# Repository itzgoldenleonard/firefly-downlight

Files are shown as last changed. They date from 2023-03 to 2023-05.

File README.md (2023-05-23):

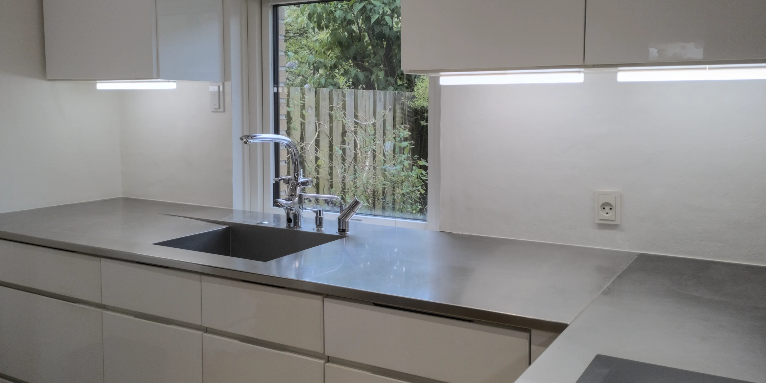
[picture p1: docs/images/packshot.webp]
Real picture of the lamps in use


# The firefly downlight

Functional, minimalist and modern downlight meant to be hung on the bottom of a cabinet or similar. Designed with kitchen use in mind but can be used wherever you like. The design is free and open source, easily moddable and 3d printable, so the barrier to manufacturing your own (customized) units is low.

## Organization

The first place you will want to look is the [`docs`](./docs) folder. Here you'll find all the information needed to do whatever you like with the project.

In the [`CAD`](./CAD) folder you'll find all of the OpenSCAD source files for the models of the actual lamp, the source files for a few optional extra tools and the libraries used in the design.

The [`Final`](./Final) folder contains the output files of the final design. That means each model has an STL 3d object file, a 3mf PrusaSlicer project file and a sliced gcode file for use with the craftbot+ 3d printer (if you have a different printer you'll need to re-slice it yourself)

Finally [`Test prints`](./Test%20prints) can mostly be ignored, it just contains tests that I used during the design process. If you're unsure that your printer's settings are correct they might be useful to test that everything fits together before printing the final parts, each test print has a markdown file associated with it explaining exactly what it contains.

## Contributing

This product is licensed under [CC-BY-SA 4.0](./LICENSE.md) which means that you have the freedom to manufacture it, study the source material, redistribute the source material and to modify it and redistribute your modified version, even for commercial purposes. As long as you give appropriate credit and redistribute your modified version under the same copyleft terms.

If you decide to make some of these lamps for yourself it would be great if you left some feedback and explained your findings. To help me or someone else improve on the design. Feedback is important so that we can know what we're doing right, what we're doing wrong, and so that we can share ideas and inspirations that foster creativity and design improvements.

If you have generally useful modifications to this project, either the design itself or the documentation, you're very welcome to make a pull request and get your additions merged into this repo. Just make sure not to use any non-free file formats or your pull request will be rejected. Also feel free to go crazy and make improvements or modifications that might not be relevant to anyone but yourself, but if it doesnt line up with my vision of the project dont expect it to be merged into **this** repo.

Be creative and make the best of it. I found out that these lamps are actually also great for soldering, so I designed a [little part](./CAD/tools/helping_hands_mount.scad) that you can use to mount it to a pair of helping hands. I'm sure there are plenty of other uses that I cant think of, so it's your turn now to do that, maybe think a little outside the box and dont be afraid to experiment.

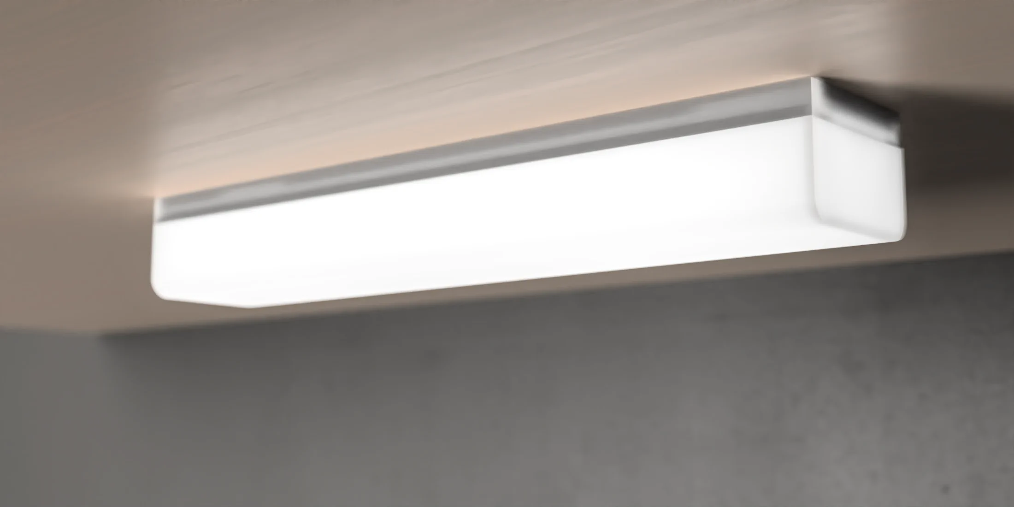
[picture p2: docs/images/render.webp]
Render of a lamp


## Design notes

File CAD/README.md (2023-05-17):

# Design files for the firefly downlight

This project is entirely made in OpenSCAD. Let me let you in on a little secret: *Openscad is pretty bad for projects of this size*. The code quality probably couldn't be much better, I've spent a long time making it as readable as possible, but I've had to get pretty hacky to get everything to work together. I'll walk you through how it all works on a high level though, if you want more detail the code itself is either pretty self explanatory or explained with comments.

## 1. Selecting the parts

It all starts in `main.scad`. This is the file you'll wanna open in OpenSCAD. There are 3 parts to a complete lamp, you can select which one you want in the customizer window in OpenSCAD. They are as follows:
- `mount` aka *lamp mount* is the part that you stick or screw to the bottom of wherever you want the lamp to hang
- `lamp` is the part that holds the metal sheet with the LED strips and wiring
- `diffuser` is the part that slides into the lamp part and prevents you from burning out your eyeballs by looking directly at the LEDs

## 2. The dimensions file

All the different files need access to a bunch of dimensions, many of which need to be shared across multiple different files. So all of the dimensions are put in the single single `dimensions.scad` file that's included (run) at the start of every other file. If you wanna change some measurements, the `dimensions.scad` file is your one stop shop. Some things might break if you change certain variables too much, so always verify that the model turned out the way you actually wanted if you change anything in `dimensions.scad`.

The dimension variables are all prefixed with D and similar dimensions are grouped together in a hashmap (called object by json) like structure. There's a function in the `utility.scad` file called `get` that can extract values of the variables inside the hashmap like structures. This is the hacky stuff I was talking about.

## 3. The lamp mount part

The code for the *lamp mount* is inside `lamp_mount.scad`. It's a relatively simple part and it only consists of primitives and a few *female mounts*. 

The distinction is between *lamp mount* and just *mount*, the *lamp mount* is the entire part that you actually print, but the *mount* (in `mount.scad`) is the sub part with the dovetails, which can be either male or female, in this case it's female. 

The mount actually also consists of a custom module called *dovetail* from the file `dovetail.scad`

## 4. The lamp part

The code for the *lamp* part is inside the aptly named `lamp.scad` file. It's considerably more complicated, it also has some *mounts*, these ones are male. 

Inside of the part is a metal *sheet*, which is obviously not 3d printed. The *sheet* is covered with some honeycomb mesh from an external library called `lib/honeycomb.scad`.

It also has some cutouts that the *diffuser* can slide into. These are actually the same dovetails (from `dovetail.scad`) that the *mounts* use, just cut in half. And that's about it.

## 5. The diffuser

The *diffuser* whose code is in `diffuser.scad` is the easiest part. It's pretty much just a single extruded 2d sketch with some *half dovetails* from `dovetail.scad` on the tips. It slides into the matching half dovetails on the *lamp* with only a single visible seam.

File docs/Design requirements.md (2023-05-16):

# Design requirements for the firefly downlights

LED strip kitchen lamps

- [ ] Durable
    - [ ] Food (and steam) resistant
    - [ ] Cleanable without taking damage
- [ ] Repairable
    - [ ] Every component needs to be easily replaceable
    - [ ] Cables need to be easy to unplug
    - [ ] Easy to install and uninstall from its place
- [ ] Beautiful
    - [ ] No external cables
    - [ ] Smooth surface
    - [ ] As few seams as possible
    - [ ] Thin
- [ ] Make good light
    - [ ] Sufficiently bright
    - [ ] Soft light
    - [ ] No light spots on the visible surface
    - [ ] Consistent color

# Problems with previous design

## Durability
- Base gets bendy
- Base becomes crunchy
- LED strips have peeled off the base
- Some of the LEDs have gone out

## Repairability
- The diffuser is hard to get off
- The base is hard to get off
- Cables aren't easy to unplug

## Visual
- Cable management has gone loose over time
- Color is inconsistent (probably the diffusers fault)

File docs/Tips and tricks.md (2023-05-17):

# What material to use

I used PLA and it worked well, but if you're worried about damage from the heat (which is a very valid concern) you should use a more heat resistant material like PETG or ASA. Obviously the diffuser needs to be printed in a white or translucent material because as much light as possible needs to pass through it, but it shouldnt be completely transparent because then it wouldnt have any effect at all. You could in theory print the other parts in a different color but I dont see why you would.

# Testing that the mount fits

The file [`Test prints/dovetail_mount_test_v1.6.tar.gz`](../Test%20prints/dovetail_mount_test_v1.6.tar.gz) contains some models a single mount that you can use to test fit the mounts on your parts individually

# Printing on top of the metal sheet

This is hard. Take a look at the [3mf file](../Final/lamp.3mf) for some inspiration. You need to get your bridging settings bang on. 

Make it print the first layer or 2 on top of the metal as solid layers and not honeycomb. The plastic coming out of the nozzle wont stick to the metal (gluestick helps but not much), only the plastic on either side of it, so it needs to touch that plastic as often as possible so that it has something to hang onto. 

I found that turning off thick bridges helped. By default it will probably want to bridge over the long side of the sheet, but playing around with the bridge flow ratio, in my case made it want to bridge over the short side of the sheet, which means that it sticks to the plastic much more often, your mileage may vary. I used a bridging speed of 45mm/s, that seemed to be not too fast but not too slow.

Another thing that helps a lot is starting with a freshly leveled bed, and when it gets to that first bridging layer, having your fingers on the bed levelling knobs and turning them while it's printing the first layer to get it to apply just the right amount of pressure. You want the plastic to come out onto the metal sheet, but you want it to be squezzed pretty hard or it wont stick. Because the sheet is never perfectly flat I needed to adjust it continously throughout the first layer. 

If you dont get a near perfect first layer it will come loose on the next layer and ruin the whole rest of the print.

# Drilling cable holes through the lamp

I used a metal sheet with holes already cut into it, so I could just use a hot needle to make the hole through the plastic. It might be smart to drill the hole in the metal sheet before inserting it into the lamp. But it shouldnt be too difficult to drill it after the fact. 

In the default configuration you have 2 LED strips on either side of the sheet with a 4mm gap between them. This leaves just enough room for a hole or 2 big enough to fit 2 dupont wires through.

# Attaching LED strips

I would suggest you drill the hole before attaching the LED strips to avoid damaging them. 

Because you're putting the LED strips directly on a conductive surface it's best to be safe and add a little strip of electrical or double sided tape between each conductive pad on the strip and the metal sheet. Also check with a multimeter that there's no connection.

The smartest way to orient the LED strips is so that one of them has the negative rail facing the middle of the lamp and the other has the positive rail facing the middle of the lamp. This makes soldering much easier.

# Soldering

I found that the best way to solder was to strip and pre-tin the wires (with flux), then attach the lamp to a solid surface and line up the wires with the pads on the LED strips. Then with a chisel tip on the iron I would heat up the pad and the wire and bring in an appropriate amount of solder, which melts quickly and flows right onto the pad, making a solid connection. Once it was soldered, then I'd route the cables through the hole out to the other side.

There's 14mm between the pads on the 2 LED strips. Prepare and pre bend the wires first, then solder like before, if you attached one end and the other doesnt quite line up there is a little wiggle room if you bend the middle of the cable.

## Connection diagram

You have to be quite precise because the height clearance is super tight. No criss crossing cables allowed or the diffuser wont fit. Here's a psuedo wiring diagram showing how I connected everything up:

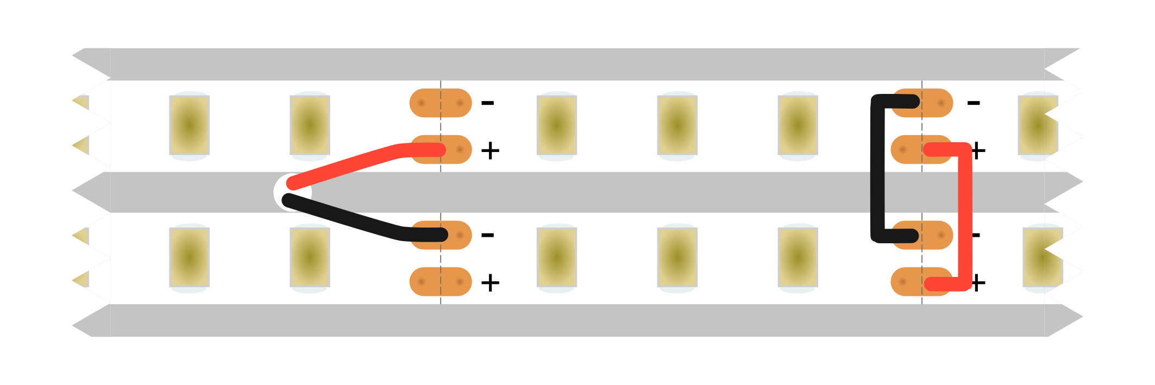
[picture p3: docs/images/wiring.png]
Wiring diagram


# Attaching connectors

Obviously you have to attach the connectors after you've soldered, I used common 0.1" dupont or jumper connectors, but maybe experiment with other connectors yourself. They kinda suck to attach because you need a crimping press to do it, but in my opinion it's well worth it when the alternative is wago connectors or soldering. You dont technically need connectors though.

# Power wire clearance

Whether you're retrofitting them onto an old cabinet or running cables specifically for these you do need to be mindful of the clearance that the power wires need. Because the lamp slides on from the side you cant just make a little circular hole in the bottom of the cabinet for the wires to go through. Additionally you will also need to fit a connector in the hole in the cabinet. You need to do some mental gymnastics to figure out the clearance. 

Imagine that the lamp is hanging and is attached to the cabinet. You need a hole that's big enough for the connectors to fit inside. But then when you go to remove the lamp you also need to extend the hole at least 25mm to the side that the lamp slides off. So make sure that the connectors also fit 25mm to the left or right of the initial hole.

Of course you also have to make sure that the wires never intersect with the individual mounts on the lamp mount, and the lamp mount needs to have a cutout that the wires can also always fit through.

# Grouping 2 together

The design is made for 2 lamps to sit right next to each other. The side that you slide the diffuser in from is a bit uglier that the other side, so that side needs to face the other lamp. When 2 lamps are grouped together like this they hide the ugly side and the left lamp slides off to the left and the right one slides off to the right, so both of them are actually possible to remove without interfering with the other one.

# Finishing

Sanding it completely smooth by hand looks very nice but also takes 10+ hours per lamp. So it's not exactly practical to do. I only sanded the rounded corners on mine and they look fine. But if you have a belt grinder you might be able to do it in a practical amount of time. Maybe try out sand blasting. Painting is probably not a good idea since the light has to shine through the plastic and the paint would probably just block it. If you have a good resin printer you might not even have to do any finishing. It depends on how picky you are with the finish, what you end up doing here. Making it with traditional plastic manufacturing methods instead of 3d printing is also a good option, although quite expensive.

# Simple/suggested mods

## Dimming

If you're concerned about overheating, or you just want to extend the life span of you LED strips I recommend that you run them at a slightly lower voltage than what they're rated for. Thermal management is one of the few untested concerns I have with these lamps, I dont have any hard data to back me up but I think the thermals are fine, I'm not 100% sure though. Especially if you've made them out of PLA dimming them a bit is probably a good idea, if nothing else least they'll last longer.

The lamps are very bright, so even at 70% brightness they're probably good enough for your needs. I personally hate PWM dimmers, and I would always suggest that you dim the proper way, which is to adjust the actual voltage that's applied to the LEDs.

## Bi color LEDs

Since there are 2 LED strips per lamp it would be an obvious mod to have 2 different color temperatures per lamp. This way you can add CCT control it does require a few extra wires, but if you drill 2 holes right next to each other that shouldnt be a problem. 

Changing the width in `dimensions.scad` is also quite easy, so if you wanted RGBCCT you could, or any other combination of 2, 3, 4 or more LED strips in each lamp.

## Screw mounting

Do you also not trust adhesive, magic tape is stupidly strong, I tested that a single mount can hold multiple kilograms, for reference one lamp weighs less than 100g and has 2 mounts holding it on, but maybe you still dont like the idea of mounting the lamps with tape. In that case it should be easy to mod the lamp mount so that it can be screwed on instead of taped. If you do you should set the `Dmount/male/tape_thickness` variable in `dimensions.scad` to `0`.

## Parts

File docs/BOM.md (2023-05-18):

I suggest making a whole batch of them. I made a batch of 12 and here is the entire list of things that I used with quantities and price (excluding shipping). You will of course also need tools. The price could be lowered further by making bigger batches or by upcycling old materials that you have lying around or gotten for free/cheap. Obviously prices will vary depending on region, some of the things on the list also contain **way** more than you need, these are just the things that I bought and might not be the best option for you, but this should still be a helpful approximation.

| Item | Quantity | Price |
|---|---|---|
| [Prusament PLA Pristine White](https://www.prusa3d.com/product/prusament-pla-pristine-white-1kg) | 1kg | 29.99€ |
| [High CRI daylight balanced LED strips](https://www.aliexpress.com/item/32855110530.html) | 5m | 30.15€ |
| [1mm stainless steel sheet (perforated)](https://www.jemogfix.dk/staalplade-1-x-500-x-400-mm-type-453/4145/9034990/) | 400x500mm | 20.00€ |
| [Magic tape](https://www.aliexpress.com/item/4001086568239.html) | 3m | 1.80€ |
| [Jumper pin header kit](https://www.aliexpress.com/item/1005002646300836.html) | 620pcs | 3.20€ |
| [Dupont wire](https://www.aliexpress.com/item/1005004611997111.html) | 40x300mm | 1.94€ |
| **Total** | **12pcs** | **87.08€** |
| **Per lamp** | **1pcs** | **7.26€** |

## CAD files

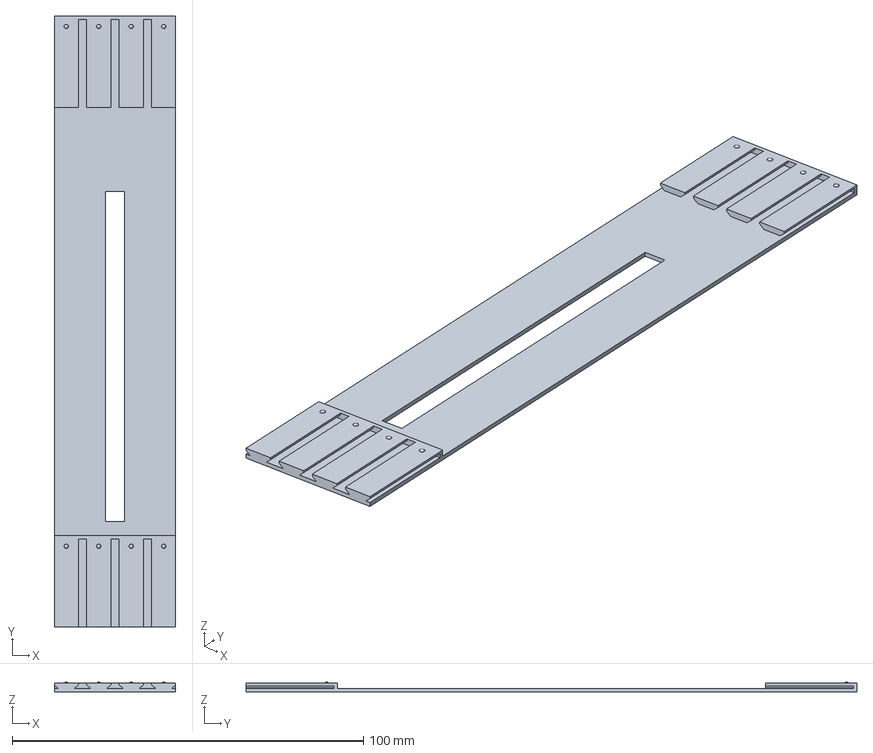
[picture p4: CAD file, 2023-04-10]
Final/lamp_mount_alt.3mf
34.6 x 174.0 x 2.85 mm

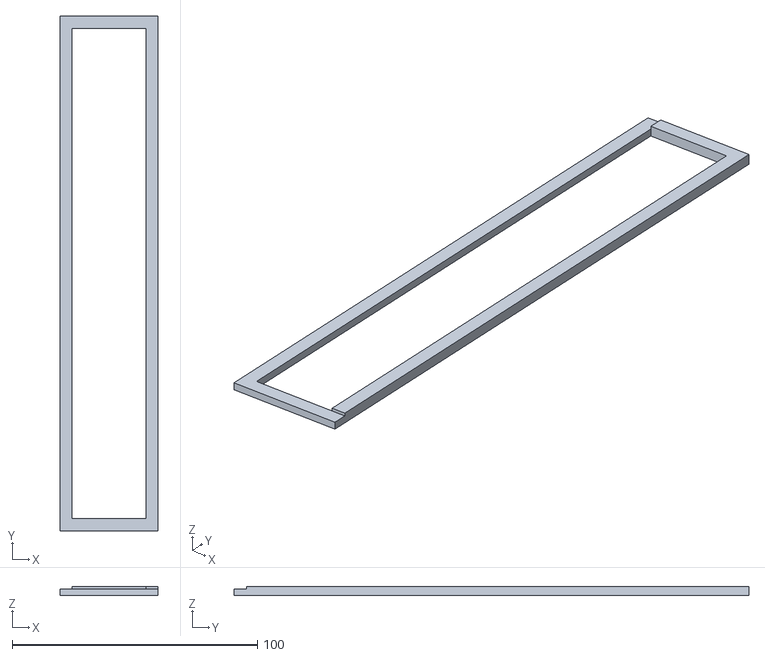
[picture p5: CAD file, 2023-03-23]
Final/Tools/sheet_template.stl
40.0 x 210.0 x 3.50

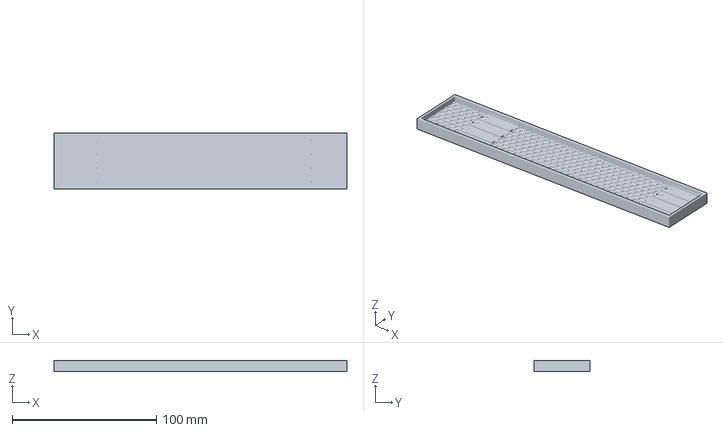
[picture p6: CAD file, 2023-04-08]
Final/lamp.3mf
203.0 x 39.0 x 7.50 mm

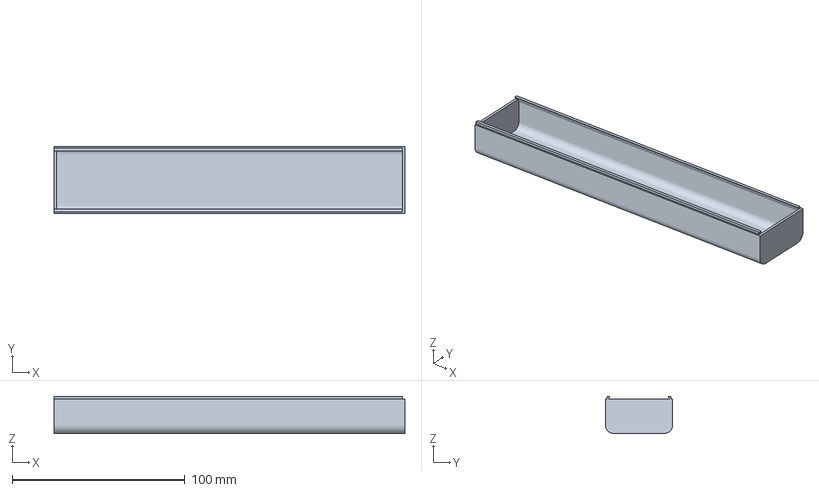
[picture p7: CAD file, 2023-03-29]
Final/diffuser.3mf
203.0 x 39.0 x 21.4 mm

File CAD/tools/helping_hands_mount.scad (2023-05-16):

/* This is a special lamp mount that attaches to helping hands for soldering
 * Turns out that without the diffuser these lamps are actually also great for soldering,
 * they just need to be held in the right place, which is exactly what this little part does
 * I dont know if it works with all models of helping hands, mine is from fixpoint. But hey,
 * that's nothing a pair of calipers and some variable changing cant fix in a few minutes
 */
$fa = 1;
$fs = $preview ? 1 : 0.15;
use <../utility.scad>
use <../mount.scad>
include <../dimensions.scad>

// Ball mount
ball_diameter = 7.2;
// Bonding cube
cube_length = 10 + get(mount_female, "width") / 2;
translate([0, -ball_diameter / 2, 0]) cube([cube_length, ball_diameter, ball_diameter]);
// Connecting cylinder, allowing for free adjustment without buming into the cube
cylinder_height = 3.8;
translate([cube_length, 0, ball_diameter / 2]) rotate([0, 90, 0]) cylinder(h = cylinder_height, d = 4.4);
// Ball head
translate([cube_length + cylinder_height + ball_diameter / 2 - 1, 0, ball_diameter / 2]) sphere(d = ball_diameter);

// Lamp mount
translate([0, -get(mount_general, "length") / 2, -get(mount_female, "height")])
mount_female();

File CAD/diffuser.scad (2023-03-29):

use <utility.scad>
use <dovetail.scad>
include <dimensions.scad>

module diffuser() {
    // This is the diffuser that slides onto the lamp. 
    // It consists of an extruded 2d shape, some dovetails and 2 end caps, which are hulls of the 2d shapes.
    D = Ddiffuser;

    mirror_x() { 
        // Main diffuser
        linear_extrude(get(Dsheet, "length")) diffuser2d(); 

        // Dovetails
        translate([get(Dlamp, "width") / 2 - get(D, "dovetail_offset"), get(D, "height"), 0]) 
        mirror([1, 0, 0]) 
        rotate([90, 0, 180]) 
        dovetail(get(Dsheet, "length") + get(Dlamp, "stoppers_thickness"), true, true);

    }
    // End caps
    for (i = [
        -get(Dlamp, "stoppers_thickness"),
        get(Dsheet, "length"),
    ]) {
        translate([0, 0, i]) 
        hull() 
        mirror_x() 
        linear_extrude(get(Dlamp, "stoppers_thickness")) {
            diffuser2d();
        }
    }
}

module diffuser2d() {
    // This is a 2D projection of the main body of the diffuser. But without the dovetails, because those are 3D.
    D = Ddiffuser;
    width = get(Dlamp, "width") / 2;

    // Bottom straight line
    square([
        width - get(D, "corner_radius"), 
        get(D, "thickness")
    ]);

    // Side straight line
    translate([
        width - get(D, "thickness"), 
        get(D, "corner_radius"), 
    0]) 
    square([
        get(D, "thickness"), 
        get(D, "height") - get(D, "corner_radius")
    ]);

    // Support for dovetails
    polygon([
        [width - get(D, "thickness"), get(D, "height")],
        [width - get(D, "thickness") - get(get(Ddovetail, "male"), "body_width") / 2, get(D, "height")],
        [width - get(D, "thickness"), get(D, "height") - get(get(Ddovetail, "male"), "body_width")],
    ]);

    // Rounded corners
    intersection() {
        translate([width, 0, 0])
        mirror([1, 0, 0])
        square(get(D, "corner_radius"));

        difference() {
            translate([width - get(D, "corner_radius"), get(D, "corner_radius"), 0]) circle(get(D, "corner_radius"));
            translate([width - get(D, "corner_radius"), get(D, "corner_radius"), 0]) circle(get(D, "corner_radius") - get(D, "thickness"));
        }
    }
}

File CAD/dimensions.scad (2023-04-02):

Ddovetail = [
    [ "male",
        [
            [ "head_height", 0.8 ],
            [ "body_width" , 2   ],
            [ "body_height", 0.6 ],
        ]
    ],
    [ "female",
        [
            [ "head_height", 1   ],
            [ "body_width" , 2.4 ],
            [ "body_height", 0.5 ],
        ]
    ],
];

Dsheet = [
    [ "width", 30 ], // 10mm for each LED strip, 4mm of space between them, 3mm on each side for the lips
    [ "length", 200 ],
    [ "thickness", 1 ],
    [ "offset", 1 ], // This is the thickness of material above the sheet
    [ "lip_width", 3], // Per lip
    [ "lip_thickness", 2],
];

Dlamp = [
    [ "width", get(Dsheet, "width") + 1 * 4 + 5 ], // 1mm on each side of the half dovetails + the approximate width of a dovetail
    [ "base_height", get(Dsheet, "offset") + get(Dsheet, "thickness") + get(Dsheet, "lip_thickness") ],
    [ "stoppers_thickness", 1.5 ],
];

// Mount
mount_general = [
    [ "length", 25 ],
    [ "locking_nubs_position", 2 ],
];

mount_male = [
    [ "wall_thickness", 2 ],
    [ "tape_thickness", 1 ], // Extra wall height
];

mount_female = [
    [ "width", get(Dlamp, "width") + (-get(mount_male, "wall_thickness") - 0.2) * 2],
    [ "height", 1 + get(get(Ddovetail, "female"), "head_height") + get(get(Ddovetail, "female"), "body_height")],
    [ "back_stop_thickness", 1 ],
];

Dmount = [
    [ "general", mount_general],
    [ "male", mount_male],
    [ "female", mount_female],
];

mounts_pos = [
    get(get(Dmount, "general"), "length") + 2,
    //get(Dsheet, "length") / 2,
    get(Dsheet, "length") - get(get(Dmount, "general"), "length"),
];

Ddiffuser = [
    [ "height", 20 ],
    [ "corner_radius", 5 ],
    [ "thickness", 1 ],
    [ "dovetail_offset", 1 ],
];

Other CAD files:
Final/lamp_mount.3mf
CAD/dovetail.scad
CAD/lamp.scad
CAD/lamp_mount.scad
CAD/main.scad
CAD/mount.scad
CAD/tools/sheet_template.scad
CAD/utility.scad
Final/diffuser.stl
Final/lamp.stl
Final/lamp_mount.stl
Final/lamp_mount_alt.stl

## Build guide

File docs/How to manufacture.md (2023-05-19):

# Print the diffuser

1. Print the diffuser in the same orientation as it will hang (big face towards the build plate). Use support on the rounded corners
2. Remove the support and use a deburring tool or knife to remove any sharp edges on the *half dovetails*. Optionally sand the rounded corners to make them look proper nice.

# Print the lamp mount

1. Print the lamp mount with the biggest face towards the build plate and the locking nubs facing away from the build plate. Dont use any support
2. Remove any sharp edges around the dovetails with a deburring tool or knife and try to insert a male mount into each of the mounts on the part, once they fit well the part is done

# Make the lamp part

1. Cut a 200mmx30mm sheet of 1mm metal (or whatever you specified in `dimensions.scad`). I've had the best luck with using an angle grinder, but a rotary tool with a cutting disc attachment works well too, it's just slower. If you have access to a CNC plasma (or powerful laser) cutter that would probably be the best option though. You can use the [`sheet_template`](../CAD/tools/sheet_template.scad) to help test the fit and score the right shape onto your metal sheet
2. Make sure that the sheet is as flat as possible. Your cutting probably left some nasty edges that need to be sanded away and chances are that your sheet is a little bit bent. Use a known flat surface and carefully bend it with your hands until it's as flat as you can possibly get it (or use a surface grinder if you have access to one). The flatness of the final lamp depends entirely on the flatness of the sheet
3. Print the lamp part in the same orientation as it will hang with the dovetail mounts pointing away from the build plate. Pause the print right before it starts printing the honeycomb grid that covers the sheet
4. Insert the sheet and continue printing, integrating the metal sheet into the plastic part. This is the trickiest part of the whole process, I suggest you read the [tips and tricks](./Tips%20and%20tricks.md) document for more info about how to do this successfully.
5. Remove sharp edges around the dovetail and test fit every mount individually with a female mount to make sure they fit well. Then do a test fit with the whole lamp mount and use sandpaper or a knife to get them to fit well together.
6. Drill and/or burn a hole through the lamp and sheet to pass the power wires though. The location depends on where the wires come out of the surface you're mounting the lamp to
7. Cut 2 lengths of LED strip and attach them to either long side of the sheet
8. Solder power wires to the LED strips and pass them through the hole from the previous step. Connect the 2 LED strips together with 2 14mm long wires. Be very careful not to touch the plastic part with your hot soldering iron, it will evaporate and leave ugly marks. Give the surface a good clean with an alcohol drenched cotton swab.
9. Attach a connector to the power wires coming out of the lamp and to the wires coming out of the bottom of the cabinet (or wherever you're mounting the lamp)
10. Test the connection

# Assembly

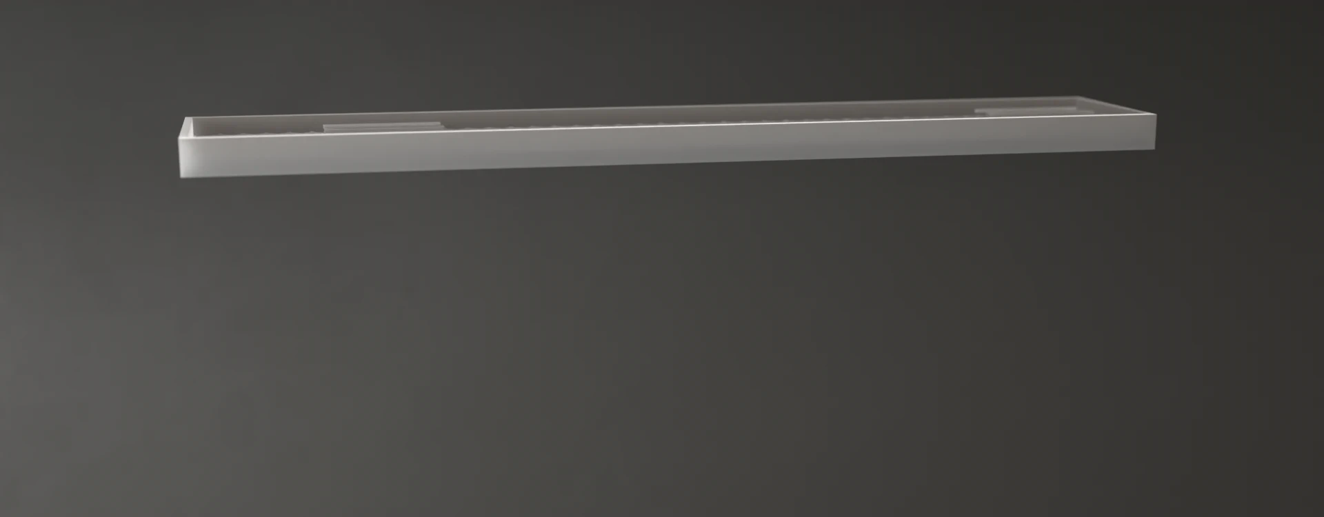
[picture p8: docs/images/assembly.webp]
Animation of assembly


1. Mark out the location on the bottom of the cabinet where you intend to place the lamp
2. Slide the diffuser onto the lamp, it might require a few light bonks with a rubber mallet, it's meant to be tight
3. Apply copious amounts of magic tape to the flat face of the lamp mount and peel the protective plastic off of the sticky side. Be careful that the tape doesnt extend over the edges though, that will make it much harder to get the lamp on and off.
4. Put the lamp mount on top of the lamp in the correct place, dont attach it properly, then the tape wont stick well enough, but be careful that it stays in the right place. Line up the lamp with your markings on the bottom of the cabinet making sure not to touch the sticky tape to the cabinet yet. Once you're sure that it's straight and lined up right apply pressure on the sticky tape and remove the lamp. Now put some pressure on the lamp mount so that the tape can stick as well as possible.
5. Slide the lamp onto the lamp mount until it clicks in place. This might also require a rubber mallet if your cabinet (or lamp) isnt perfectly flat, that's okay it's plenty durable (it can hold several kgs, I tested it).

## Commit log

2023-03-07 Snap fit test 1.0
    [Lamp.scad]
2023-03-07 Snap fit test 1.1
    [Lamp.scad]
2023-03-07 Snap fit test 1.2
    [Lamp.scad]
2023-03-09 Dovetail test v1.0
    [Lamp.scad]
2023-03-09 Dovetail test v1.1
    [Lamp.scad]
2023-03-09 Dovetail test v1.2
    [Lamp.scad]
2023-03-12 Dovetail test v1.3
    [Lamp.scad]
2023-03-12 Dovetail test v1.4
    [Lamp.scad]
2023-03-12 Dovetail test v1.5, finally got it!
    [Lamp.scad]
2023-03-12 Cleaned up dovetail code
    [Lamp.scad]
2023-03-16 Cleaned up mount code
    [Lamp.scad]
2023-03-16 Cleaned up lamp mount code
    [Lamp.scad]
2023-03-16 Cleaned up mount code a bit more
    [Lamp.scad]
2023-03-17 Dovetail mount strength test (not complete)
2023-03-17 Dovetail mount strength test (complete)
2023-03-17 Split code up into multiple files and moved dimensions into hashmaps
    [dovetail.scad, main.scad, mount.scad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]
2023-03-21 Moved all dimensions into their own file
    [dimensions.scad, dovetail.scad, lamp.scad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]
2023-03-21 Sketch for lamp module
    [dimensions.scad, lamp.scad]
2023-03-22 Made the lamp a bit less wide
    [Lamp.scad, dimensions.scad, lamp.scad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]
2023-03-22 Made the lamp walls a bit smarter and added TODOs
    [dimensions.scad, lamp.scad, main.scad]
2023-03-23 Solved most of the TODOs
    [dimensions.scad, lamp.scad, mount.scad]
2023-03-23 Honeycomb no longer intersects with locking nub holes
    [lamp.scad]
2023-03-23 Sheet template tool
    [lamp.stl, sheet_template.scad, sheet_template.stl]
2023-03-24 Made lamp.scad considerably more readable
    [dimensions.scad, lamp.scad]
2023-03-24 Added lamp_mount
    [lamp.stl, lamp_mount.scad, lamp_mount.stl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]
2023-03-28 Modified lamp slightly
    [dimensions.scad, lamp.scad, lamp.stl]
2023-03-28 These aren't quite right
    [lamp.3mf, lamp_mount.3mf]
2023-03-28 These should be better
    [lamp.3mf]
2023-03-28 First diffuser test
    [diffuser.scad, dimensions.scad, lamp.scad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]
2023-03-28 Second diffuser test
    [diffuser.scad, dimensions.scad]
2023-03-29 Dovetail for diffuser in lamp now actually works
    [lamp.3mf, lamp.scad, lamp.stl]
2023-03-29 Diffuser final model
    [diffuser.3mf, diffuser.scad, diffuser.stl]
2023-03-29 Figured out how to print the rounded corners properly
    [diffuser.3mf]
2023-03-29 Cleaned up diffuser code a bit
    [diffuser.scad]
2023-04-02 Removed a mount from the lamp to make room for cables
    [dimensions.scad, lamp.3mf, lamp.stl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]
2023-04-02 Increased tape height
    [dimensions.scad, lamp.3mf, lamp.stl]
2023-04-08 changed elephants foot compensation
    [lamp.3mf]
2023-04-10 Added an alternative lamp_mount
    [lamp_mount_alt.3mf, lamp_mount_alt.stl]
2023-05-16 Added README and LICENSE
    [helping_hands_mount.scad]
2023-05-16 Explained the CAD file structure on a high level
2023-05-17 How to guide
    [sheet_template.scad]
2023-05-17 Fixed wiring diagram image
2023-05-18 Added BOM
2023-05-19 Added assembly image
